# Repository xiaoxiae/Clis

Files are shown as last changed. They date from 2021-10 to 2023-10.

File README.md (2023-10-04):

_Project is **archived** and being reworked into something better. Soon launching at http://climbuddy.com/!_

---

<p align="center" width="100%">

</p>

<p align="center" width="100%">
The <strong>cli</strong>mber's <strong>s</strong>canner – efficient 3D scanning of climbing holds and climbing gym interiors.
</p>

## Introduction
This project contains everything you need to efficiently scan large set of holds (or other 3D objects, for that matter, if forked and adjusted accordingly) in a small amount of time. It uses an Arduino-powered turntable and camera to automatically take pictures, which it then converts to 3D models using the [Agisoft Metashape](https://www.agisoft.com/) photogrammetry software.

Additionally, it contains a tutorial for scanning climbing gym interiors, both of which can then be used in [Cled – the climber's editor](https://github.com/xiaoxiae/Cled).

For additional information, see the [thesis](https://github.com/xiaoxiae/Thesis).

## Setting up
For the setup, you'll need to first install `pyenv`:

```
# make sure to read what the script does before running it!
curl https://pyenv.run | bash
```

and configure your shell's environment: https://github.com/pyenv/pyenv#basic-github-checkout

You'll then need to install Python `3.7.x` (due to Metashape and Blender working only with older Python versions):

```
pyenv install -v 3.7.12
```

To set up the virtual environment, do (in this directory):

```
pyenv virtualenv 3.7.12 clis
pyenv local clis
pyenv activate clis
pyenv exec pip install -r requirements.txt
pyenv exec bpy_post_install # finds Blender and copies over some of its scripts
```

## Contents
Before running the scripts (using `pyenv exec`), it is advisable to check `config.py`, since a lot of the values will most likely differ from their default values for your particular setup.
Each of the respective folders contain a `README.md` that further explains the usage of each of the scripts.

### `01-scanning/`
Contains tools for scanning the holds.

### `02-processing/`
Contains tools for processing the hold images into 3D models.

### `03-data/`
Contains the hold data format specification and tools for managing the 3D models.

## Usage

### Using tasks
To simplify the usage of Clis, various pre-programmed scripts have been added:

- `tasks/add_models.sh` - model the newly added scans.
- `tasks/convert_from_raw.sh` - convert the raw copied files from RAW
- `tasks/copy_from_camera.sh` - copy the scanned sets from the camera
- `tasks/copy_from_path.sh <path>` - copy the scanned sets from the given path
- `tasks/generate_models.sh` - add the newly created models to the `holds.yaml` file.
- `tasks/mask_from_file_list.sh <file>` - mask the folders in the lines of the given text file
- `tasks/move_from_camera.sh` - move the scanned sets from the camera
- `tasks/scan_multiple.sh` - start scanning indefinitely
- `tasks/scan_single.sh` - scan a single time

To create a single model using them, you could do the following:
1. `./scan_single.sh` to scan a single hold,
2. `./move_from_camera.sh` to move the hold photos from the camera,
3. `./convert_from_raw.sh` to convert the photos to a usable format,
4. `./generate_models.sh` to generate the model and finally
5. `./add_models.sh` to add the model to the `holds.yaml` file.

### Using scripts
Run

```
pyenv exec python 01-scanning/01-scan.py automatic 15 && pyenv exec python 01-scanning/02-copy.py camera && pyenv exec python 01-scanning/03-convert.py
```

to automatically take 15 pictures of the hold, copy them from the camera and convert them from raw.
If you want to take them manually because you don't have the turntable, replace `automatic` with `manual`. Then run

```
pyenv exec python 02-processing/01-model.py
```

to generate the model.
Finally, run

```
pyenv exec python 03-data/01-add_models.py
```

to add the information about the hold to the `holds.yaml` dictionary.

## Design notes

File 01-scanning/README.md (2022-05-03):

# Scanning

## Scripts
The following describes the order in which the scripts should be called and what they do.

### `01-scan.py`
Scans the hold either automatically using the turntable (in which case it expects to be connected to it), or manually.
It must be connected to a camera that is supported by [gphoto2](http://gphoto.org/) (see [supported cameras](http://gphoto.org/proj/libgphoto2/support.php)).

### `02-copy.py`
Copies over the images from a local (user-readable) path, or the camera itself (connected via USB).

### `03-convert.py`
Converts the RAW hold photos to an image format (likely JPG) used for creating the models.
Uses [Darktable](https://www.darktable.org/)-CLI to do so.

### `04-mask.py`
Masks the images using the green color of the turntable.
Expects the list of files to do this to as a parameter.
Uses [OpenCV](https://pypi.org/project/opencv-python/) and [pyexiv2](https://github.com/LeoHsiao1/pyexiv2) (for metadata perservation).

## Turntable

### `markers/`
A folder containing a PDF with all 12-bit markers used for the scanning, along with their 3D models.

### `turntable/`
A folder containing the source code/documentation for the custom turntable used for turning the holds.

## `tutorials/`
Contais notes about scanning both the holds and the wall.

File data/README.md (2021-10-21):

# Data
The specification of the data format used for the climbing holds and the climbing wall.

## `holds.yaml`
A dictionary containing data of all holds.

```yaml
- Name: <hold name - sha256sum of the file>
  Color: <blue, yellow,...]>
  Type: <crimp, jug, sloper, pinch, pocket, foothold>
  Manufacturer: <the name of the manufacturer>
  Labels: [<a list of custom labels>]
```

## `holds/`
A folder containing the models of the holds in the `obj` format. Each should be:

- properly sized to correspond to the real world
- having correct origin (either in the middle or in some screw hole)
- facing upwards

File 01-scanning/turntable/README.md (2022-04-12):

# Turntable
A custom turntable powered by Arduino Uno.

Some numbers of the components vary (namely the motors), depending on how powerful you want the turntable to be, with the minimum being 1 and maximum being 3.

## Components
- 1x Arduino Uno (or some other Arduino with enough pins)
- 1x-3x A4988-based motor drivers
- 1x-3x bipolar stepper motors with a NEMA 17 interface
	- note: the length of mine is ~64mm (including the shaft), which is likely not standard; if you wish to use a different-sized NEMA 17 motor, edit the model accordingly (either the stl directly, or `parts/Turntable.f3d` in Fusion 360)
- 4x-12x M3 screws (motor mounts to motors), thread length 0.5cm
- 2x-6x M3 screws (motor mounts to body), thread length 1cm
- 2x-6x M3 nuts (motor mounts to body)
- 1x power supply for the motor(s)
- 1x superglue (if things don't fit properly)
- 7x 608 bearings

## Construction
1. print parts of the printer (found in the `parts/` folder):
	- 1x body
	- 1x top
	- 1x-3x motor mount
	- 1x-3x motor gear
2. add the bearings
3. put the mounts and gears on the motors (possibly using superglue)
4. wire and power everything
	- I used a small breadboard to make this step as easy as possible
	- Arduino expects the following mapping of pins to the A4988 sensor(s):
		- `2` -> `DIR`
		- `3` -> `STEP`
		- `4` -> `ENABLE`

<p align="center">
  Turntable Wiring Diagram
</p>

5. **tune the controllers:** https://ardufocus.com/howto/a4988-motor-current-tuning/
6. load the code to the Arduino (found in the `code/` folder)

After this, the Arduino can be controlled as seen in the `code/code.ino` script: it listens on the serial channel for the next string that it then converts to an integer and uses it as the turning angle. After the turning is done, it responds back with the same number it received (again as a string) and again starts to listen.

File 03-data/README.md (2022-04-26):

# Data

## Specification
The specification of the data format used for the climbing holds and the climbing wall:

```yaml
<sha256sum of the file contents (the first 12 characters)>:
  color: [<name of the color>, <hex value of the color>]
  type: <the type of hold (like crimp, jug, sloper, pinch, pocket, foothold, structure, etc.)>
  date: <the date the hold model was created>
  manufacturer: <the name of the manufacturer>
  labels: [<list>, <of>, <custom>, <labels>]
  volume: <a float volume of the hold>
```

## `01-add_models.py`
A script for adding the generated holds into the `holds.yaml` dictionary, automatically inferring their color from the texture in the process.

## `02-get-volume.py`
Calculate the volume of the given `obj` file, printing it to standard output.

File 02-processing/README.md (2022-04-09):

# Processing

## `01-model.py`
A script that converts sets of photos to models using [Agisoft Metashape Pro](https://www.agisoft.com/).
Only converts sets that don't yet have corresponding model folder.

## `02-clean.py`
A script that takes the model produced by Metashape and outputs the same model with the ground removed and simplified to a reasonable size.
It is _not meant to be called alone_ and is instead used in `01-model.py`.

## `03-retexture.py`
A script that takes the model and retextures it by reimporting it back to Metashape.

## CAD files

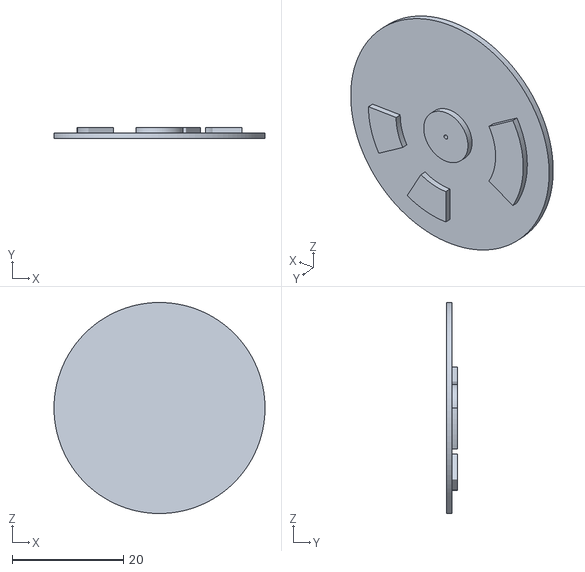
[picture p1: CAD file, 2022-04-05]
01-scanning/markers/models/9.stl
38.0 x 2.00 x 38.0

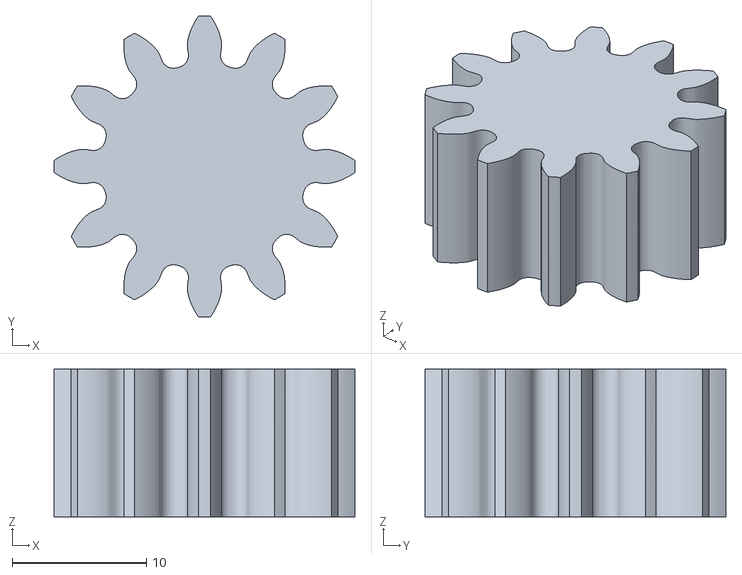
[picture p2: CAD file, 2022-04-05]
01-scanning/turntable/parts/Motor Gear.stl
22.4 x 22.4 x 11.0

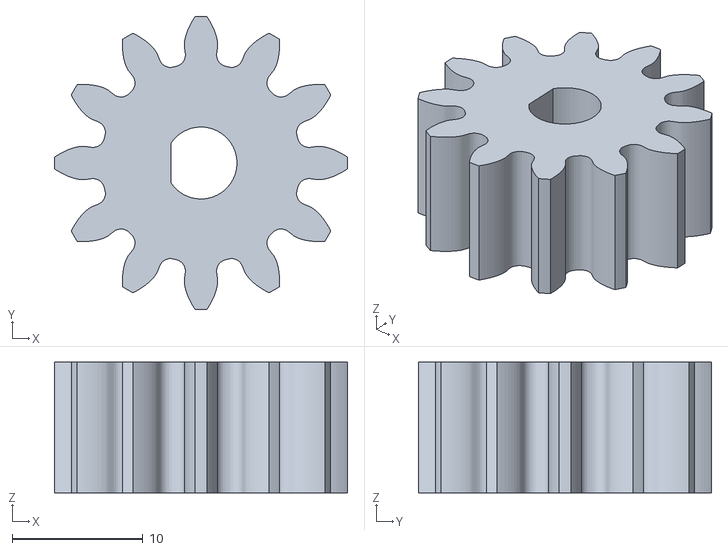
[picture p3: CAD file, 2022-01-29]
01-scanning/turntable/parts/Gear.stl
22.4 x 22.4 x 10.0

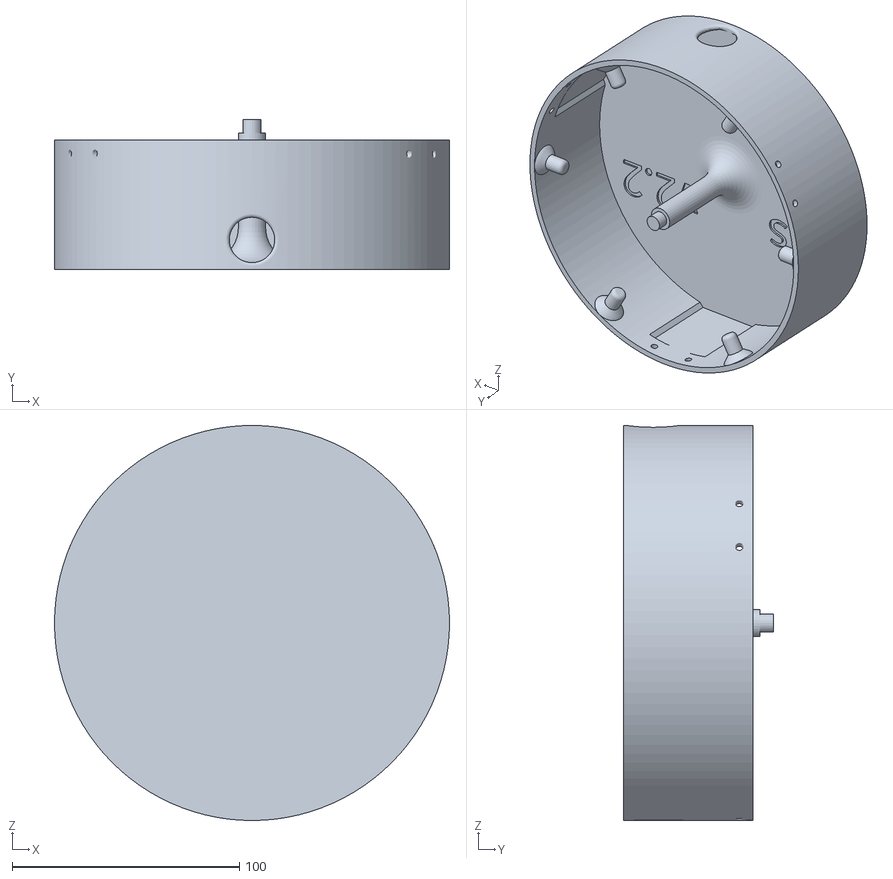
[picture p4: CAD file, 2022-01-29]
01-scanning/turntable/parts/Body.stl
174.0 x 66.0 x 174.0

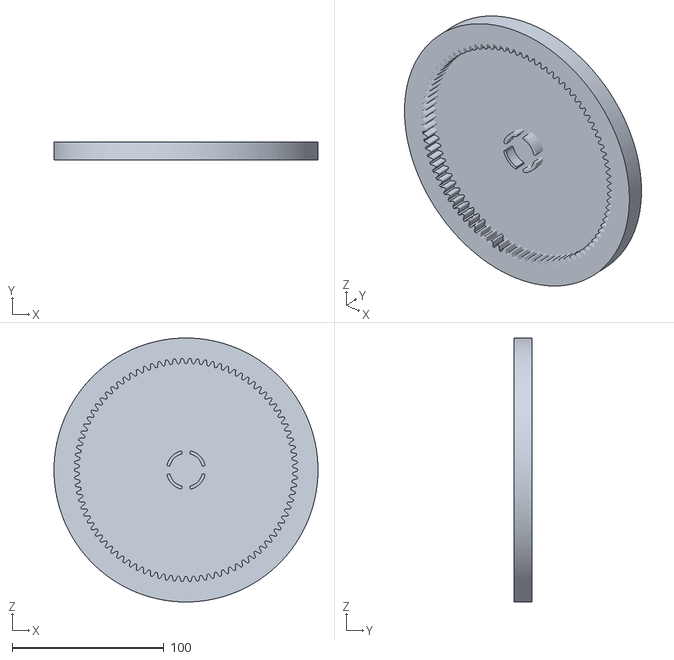
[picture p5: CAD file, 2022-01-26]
01-scanning/turntable/parts/Top.stl
174.0 x 12.0 x 174.0

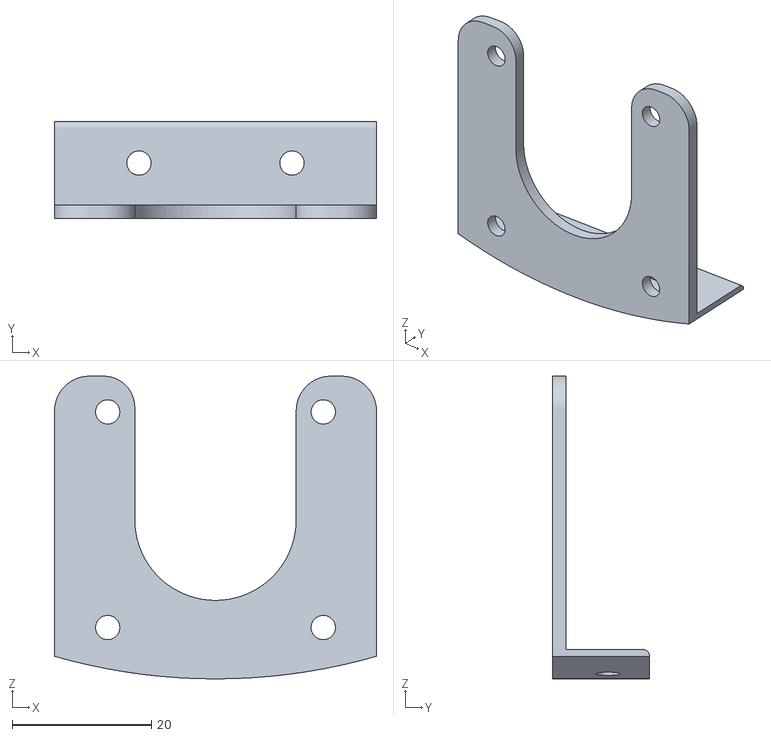
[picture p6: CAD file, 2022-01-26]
01-scanning/turntable/parts/Motor Mount.stl
46.3 x 14.0 x 43.5

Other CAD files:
01-scanning/markers/models/3.stl
01-scanning/markers/models/11.stl
01-scanning/markers/models/4.stl
01-scanning/markers/models/5.stl
01-scanning/markers/models/6.stl
01-scanning/markers/models/12.stl
01-scanning/markers/models/2.stl
01-scanning/markers/models/1.stl
01-scanning/markers/models/10.stl
01-scanning/markers/models/7.stl
01-scanning/markers/models/8.stl

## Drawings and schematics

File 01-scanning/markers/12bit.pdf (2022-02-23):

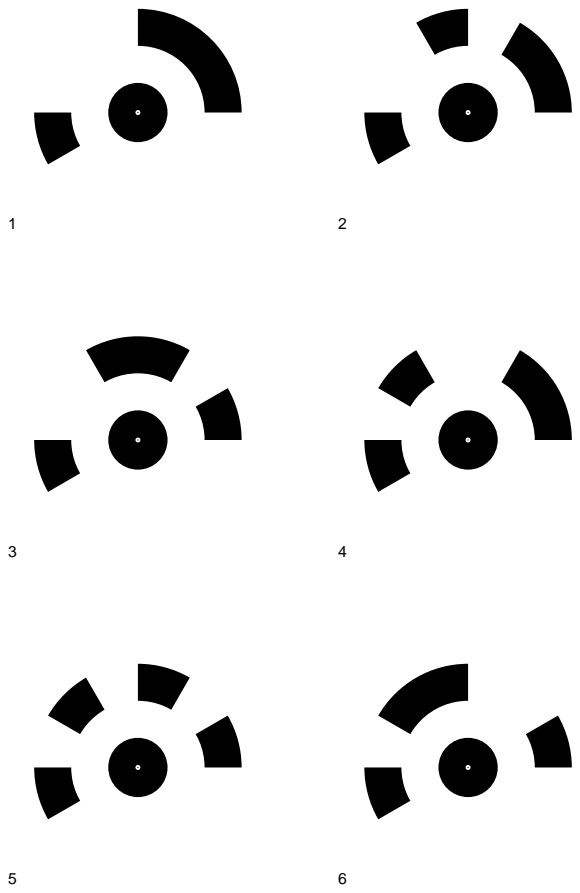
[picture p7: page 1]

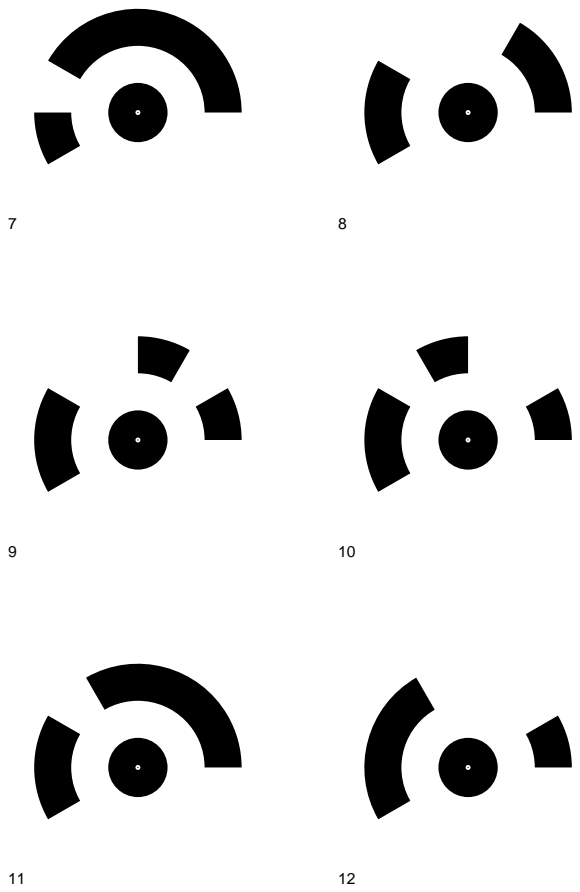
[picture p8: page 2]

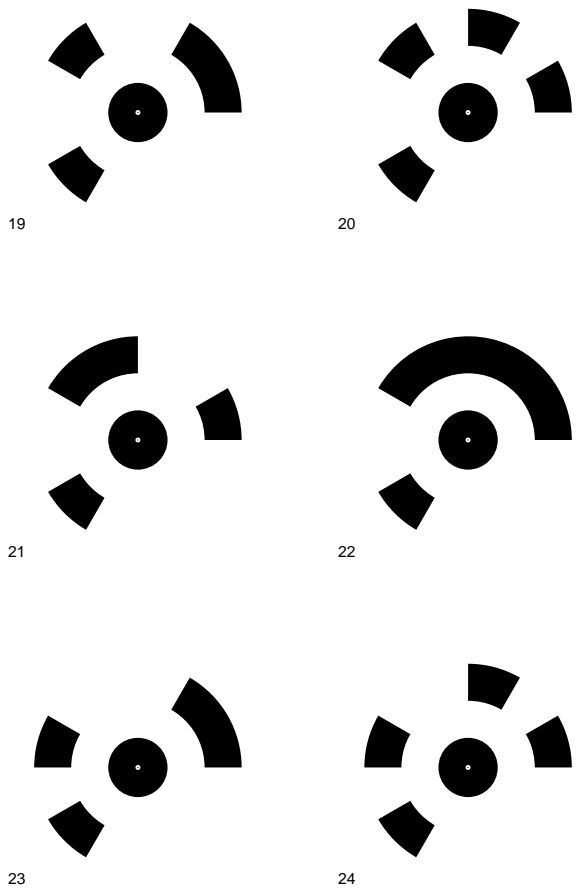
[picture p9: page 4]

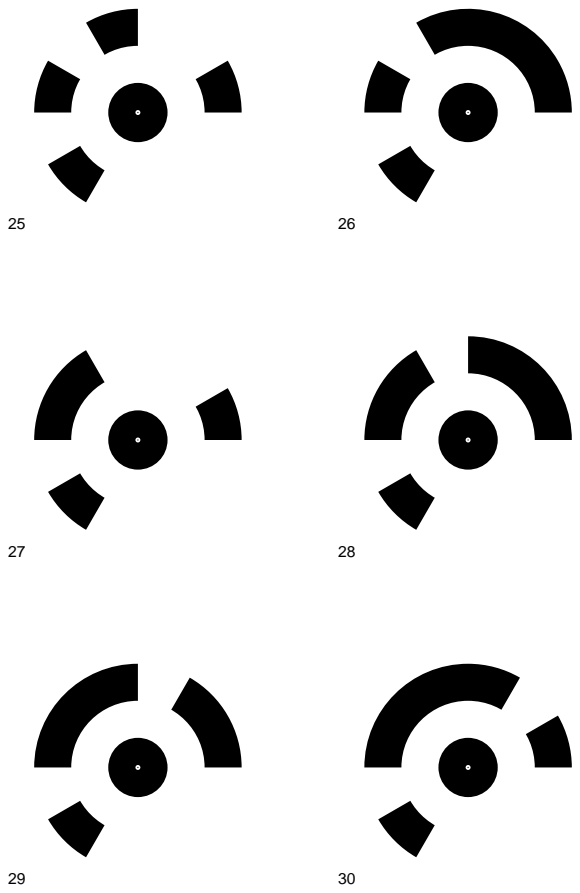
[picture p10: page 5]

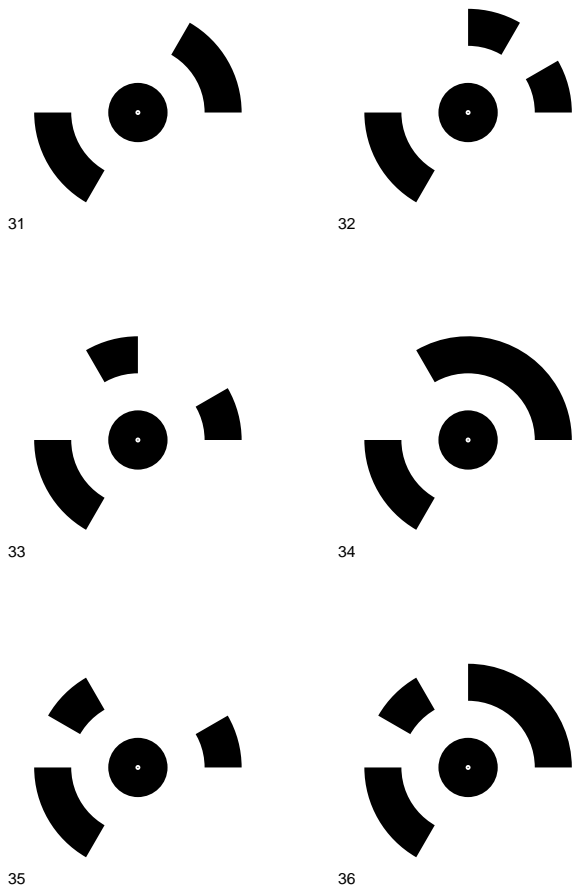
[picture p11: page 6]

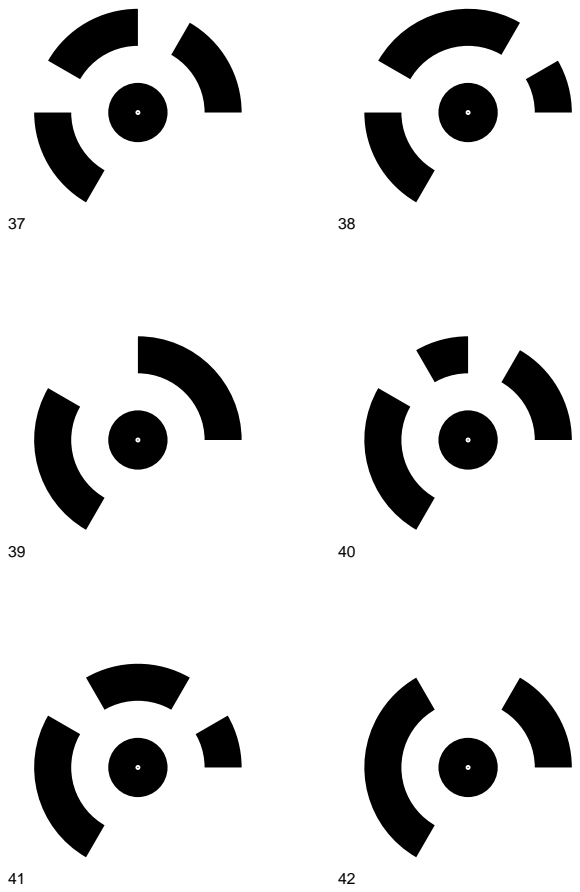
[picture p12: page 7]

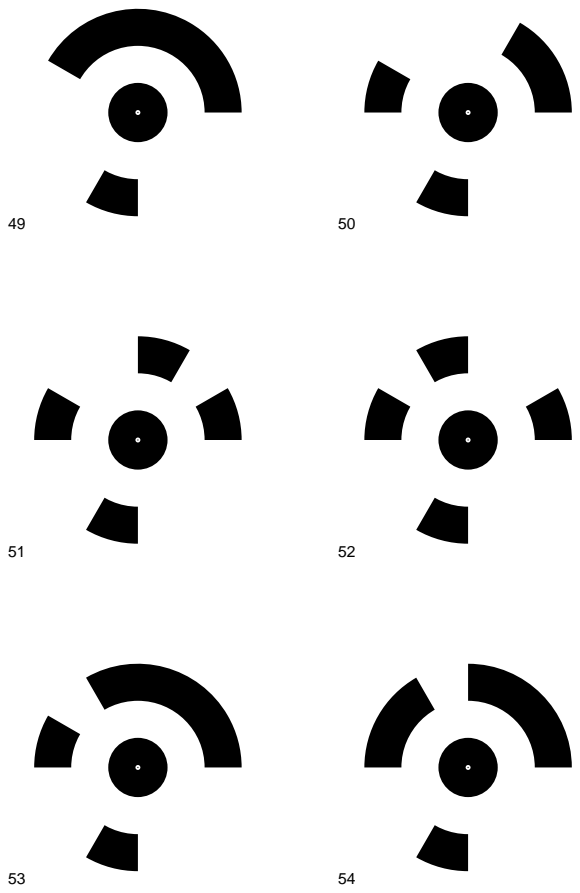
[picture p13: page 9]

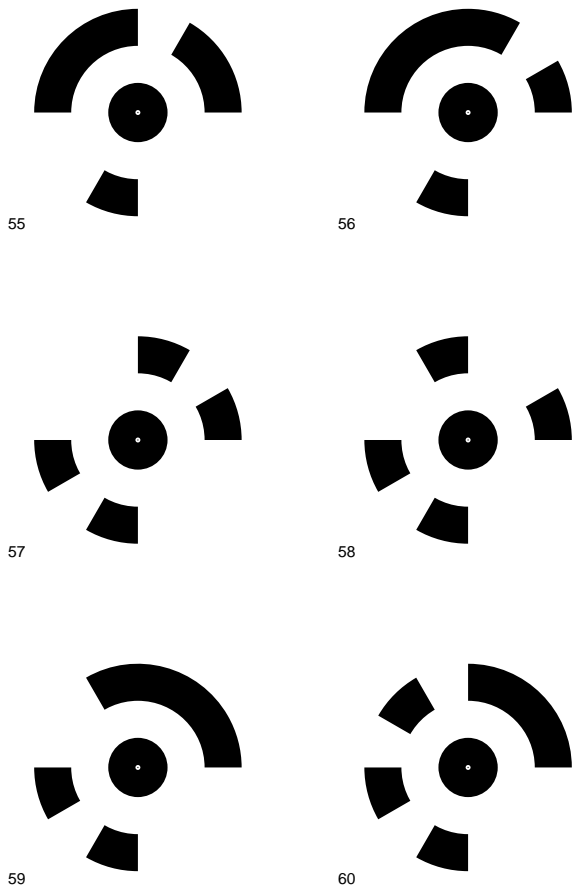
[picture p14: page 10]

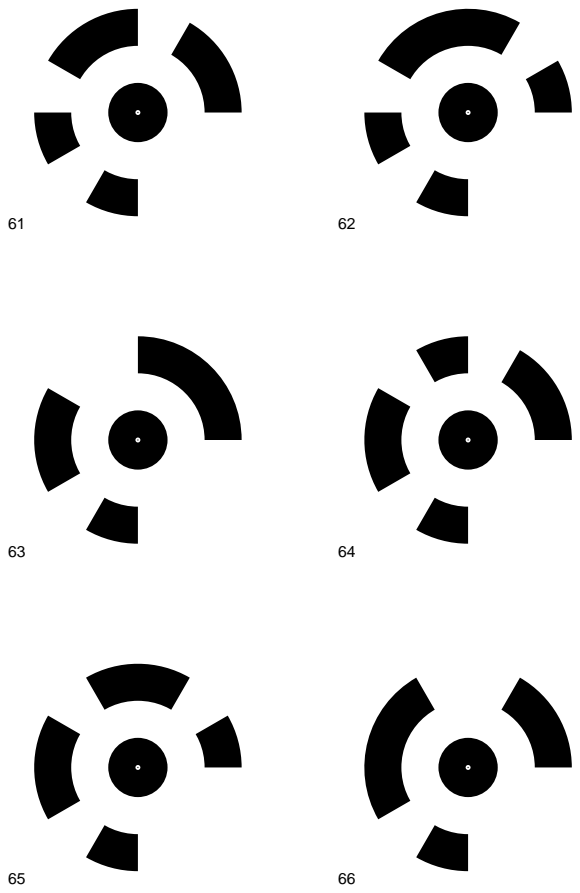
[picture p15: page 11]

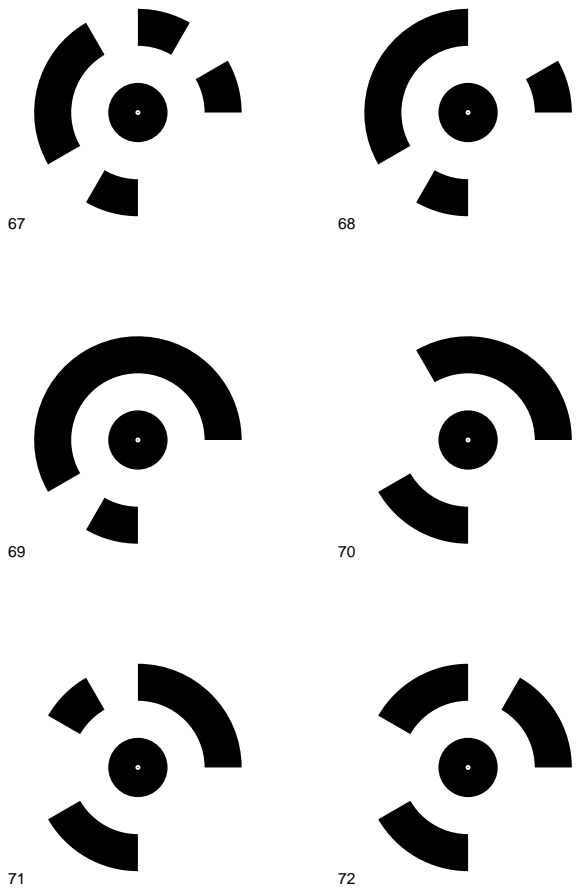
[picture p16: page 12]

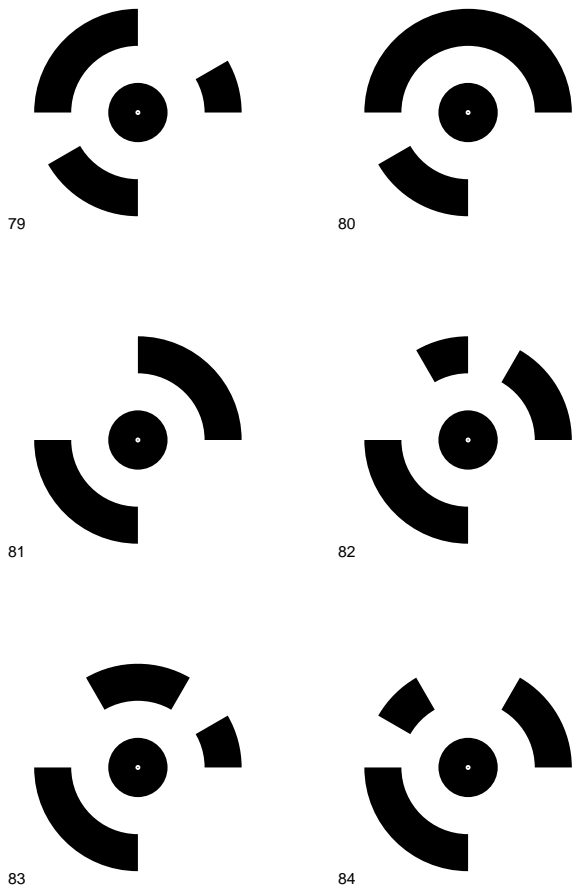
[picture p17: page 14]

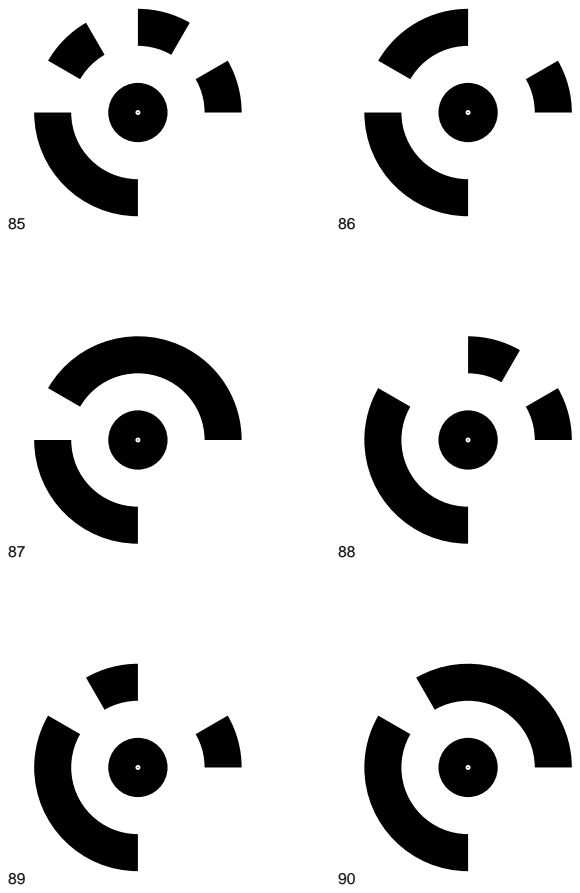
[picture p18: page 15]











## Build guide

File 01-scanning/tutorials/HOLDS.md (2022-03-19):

# Scanning climbing holds
A short tutorial on how to do photogrammetry on various types of climbing holds. Most of this is my personal opinion, formed by experimentation and various blog posts / YouTube videos about photogrammetry, so take it with a grain of salt.

I will leave links to the resources that I used while figuring things out where appropriate.

## Software used
The software used is [Agisoft Metashape Pro](https://www.agisoft.com/) using its Python bindings (see `../02-processing/README.md`). The program is relatively intuitive and simple to use, so I won't go into any detail regarding its GUI (there are many good tutorials out there that you can use if you're interested). You also likely won't need the GUI at all, since the scripts take care of everything.

## Setup
This approach covers **turntable-based photogrammetry**, meaning that the holds are on a turntable that is being captured by a stationary camera. This is essentially the same thing as turning the camera around the object (although arguably less convenient), since the background is uniform and the software has no way of telling the difference.

### Camera
I'm using the [Nikon Z 50](https://en.wikipedia.org/wiki/Nikon_Z_50) mirrorless camera to take the pictures and would suggest you use a camera too – while mobile phones produce fine photos, nothing can beat a good camera. Besides the quality of the images, it is also **extremely important** for the cameras to **contain metadata** about how the photo was taken (focal length, shutter speed, ISO, f/s), which is very useful to the photogrammetry process.

You should generally strive for low ISO (duh) and higher f/s, because you want the depth of field to be as large as possible – this makes it easier for the software to recognize key features to match between the photos, you really don't want the blur. Luckily, since (most) of the holds don't move, slower shutter speeds are quite acceptable to achive both low ISO and high f/s.

### Background
I'm using black background with a green turntable. The colors themselves aren't too important, but should be decently contrasting to the object being scanned – green holds on a green background could give the software some trouble.

### Markers
Besides the background, I use 3 markers to automatically adjust the object into its proper scale and location. This can be done quite trivially in the `Markers/` Metashape menu, where you can both generate a set of markers of desired size and also detect them in the images.

### Lighting
It is absolutely vital for the holds to be decently lit by **soft light**, ideally from multiple directions. This can be achieved by some less powerful LED lights (at most 20W) and appropriate mounting equipment. When bought right, this can be relatively cheap, but improve the quality of the scans by a large margin.

If the lights still produce light that is too hard, I'd suggest you put baking paper (or any other not-easily-flammable material) around them to better diffuse the light. This is miles cheaper than any diffuse filter you find on the market but yields similar results.

## On scanning various holds

### Dual-texture holds
When scanning dual-texture holds (and glassy holds in general), the software will have trouble finding enough features to produce a good model in the glossy area. To prevent this, I'd suggest you apply small amounts of chalk on the glossy parts.

### Large volumes
There is a pretty decent chance that you'll have to scan them outside the turnable, since they will be too large. I'd recommend placing them somwehere flat and again using markers to include in the images, since this means that you'll only have to do the "taking photos" part manually (using `01-scan.py manual`).

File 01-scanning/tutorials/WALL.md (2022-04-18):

# Scanning climbing walls
A short tutorial on how to do photogrammetry on various types of climbing walls. Most of this is my personal opinion, formed by experimentation and various blog posts / YouTube videos about photogrammetry, so take it with a grain of salt.

I will leave links to the resources that I used while figuring things out where appropriate.

## Overview
The basic idea is the following:
1. take photos of the wall
2. create a model some photogrammetry software (like [Metashape](https://www.agisoft.com/))
3. clean up the model using some 3D modelling software (like Blender)

Using this method, I managed to create a very detailed 3D model of the [Smíchoff climbing wall](https://www.lezeckecentrum.cz/cs/) in about 10 hours of work.

## Taking photos
Taking photos is the most crucial part of the entire process, since their quality will largely determine how accurate the model will be.

Use any device you can, but obviously the higher quality the better (I used my Nikon z50). When doing so, there are a few things to keep in mind:
- use different overlapping angles of each area you're capturing so the photogrammetry software has an easier time figuring everything out
- **do not change the area** that you're capturing by having people around or moving things about, else the reconstruction will most likely fail (or will exclude a lot of images, making the model inaccurate)
- the settings (ISO, shutter speed) and even the devices can differ between individual shots, but the photos should be as clear as possible and *should include the metadata** (namely the focal length), since the photogrammetry software uses this information to calculate the features

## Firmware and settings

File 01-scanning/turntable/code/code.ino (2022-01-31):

#include <AccelStepper.h>

#define dirPin1 2
#define stepPin1 3
#define enablePin1 4
#define dirPin2 5
#define stepPin2 6
#define enablePin2 7
#define dirPin3 8
#define stepPin3 9
#define enablePin3 10

#define motorInterfaceType 1

#define stepsPerRevolution 200
#define gearRatio 90.0f / 12.0f
#define angleCoefficient (int)(stepsPerRevolution * gearRatio)


#define max_speed 300.0
#define max_acceleration 400.0
#define speed_coefficient 0.8

AccelStepper stepper1 = AccelStepper(motorInterfaceType, stepPin1, dirPin1);
AccelStepper stepper2 = AccelStepper(motorInterfaceType, stepPin2, dirPin2);
AccelStepper stepper3 = AccelStepper(motorInterfaceType, stepPin3, dirPin3);


void enable_motor() {
  digitalWrite(enablePin1, LOW);
  digitalWrite(enablePin2, LOW);
  digitalWrite(enablePin3, LOW);
}

void disable_motor() {
  digitalWrite(enablePin1, HIGH);
  digitalWrite(enablePin2, HIGH);
  digitalWrite(enablePin3, HIGH);
}


void setup() {
  stepper1.setMaxSpeed(max_speed);
  stepper1.setAcceleration(max_acceleration);
  stepper1.setSpeed(max_speed * speed_coefficient);
  
  stepper2.setMaxSpeed(max_speed);
  stepper2.setAcceleration(max_acceleration);
  stepper2.setSpeed(max_speed * speed_coefficient);
  
  stepper3.setMaxSpeed(max_speed);
  stepper3.setAcceleration(max_acceleration);
  stepper3.setSpeed(max_speed * speed_coefficient);

  pinMode(enablePin1, OUTPUT);
  pinMode(enablePin2, OUTPUT);
  pinMode(enablePin3, OUTPUT);

  disable_motor();

  Serial.begin(9600);
}

int angleToRevolutions(int angle) {
  return (int)((angle / 360.0) * angleCoefficient);
}

void loop() {
  if (Serial.available() > 0) {
    long angle = Serial.readString().toInt();

    enable_motor();
    stepper1.setCurrentPosition(0);
    stepper1.moveTo(angleToRevolutions(angle));
    
    stepper2.setCurrentPosition(0);
    stepper2.moveTo(angleToRevolutions(angle));
    
    stepper3.setCurrentPosition(0);
    stepper3.moveTo(angleToRevolutions(angle));

    while (stepper1.distanceToGo() > 0 && stepper2.distanceToGo() > 0 && stepper3.distanceToGo() > 0) {
      stepper1.run();
      stepper2.run();
      stepper3.run();
    }
    
    disable_motor();

    Serial.println(angle, DEC);
  }
}

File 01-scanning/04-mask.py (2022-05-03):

import cv2
import numpy as np
import shutil
import sys
import os
import argparse
import pyexiv2
import tempfile
from subprocess import Popen, PIPE
from glob import glob

sys.path.append("..")

os.chdir(os.path.dirname(os.path.abspath(__file__)))

from config import *
from utilities import *


def get_convex_hull_mask(image):
    """Get the mask using the convex hull of green pixels. Currently unused (but kept as a pet)."""
    hsv = cv2.cvtColor(image, cv2.COLOR_BGR2HSV)

    lower_green = np.array([65,60,60])
    upper_green = np.array([80,255,255])

    mask = cv2.inRange(hsv, lower_green, upper_green)

    kernel = np.ones((5,5),'int')
    dilated = cv2.dilate(mask,kernel)

    res = cv2.bitwise_and(image,image, mask=mask)

    ret, thresh = cv2.threshold(cv2.cvtColor(res,cv2.COLOR_BGR2GRAY),3,255,cv2.THRESH_BINARY)
    contours, hierarchy = cv2.findContours(thresh, cv2.RETR_LIST, cv2.CHAIN_APPROX_SIMPLE)

    # create hull array for convex hull points
    hull = []
    for contour in contours:
        hull += list(contour)

    hull = cv2.convexHull(np.array(hull), False)
    hull = np.array([[h[0] for h in hull]])

    # create an empty black image
    drawing = np.zeros(image.shape[:2], np.uint8)

    cv2.fillPoly(drawing, hull, (255, 255, 255))

    return drawing


def get_contour_mask(image):
    """Get the image by using contours from the pixel threshold."""
    gray = cv2.cvtColor(image, cv2.COLOR_BGR2GRAY)

    ret, thresh = cv2.threshold(gray, MASKING_THRESHOLD, 255, cv2.THRESH_BINARY)

    # detect the contours on the binary image using cv2.CHAIN_APPROX_NONE
    contours, hierarchy = cv2.findContours(image=thresh, mode=cv2.RETR_TREE, method=cv2.CHAIN_APPROX_NONE)

    # find the biggest countour (c) by the area
    c = max(contours, key = cv2.contourArea)

    # create an empty black image
    drawing = np.zeros(image.shape[:2], np.uint8)
    cv2.fillPoly(drawing, np.array(c), (255, 255, 255))

    # flood fill from origin on black pixels
    cv2.floodFill(drawing, None,
            seedPoint=(image.shape[1] // 2, image.shape[0] // 2),
            newVal=(255, 255, 255),
            loDiff=(1, 1, 1, 1), upDiff=(1, 1, 1, 1))

    # smoothen a bit
    kernel2 = np.ones((5, 5), np.float32)/25
    img = cv2.filter2D(src=drawing, ddepth=-1, kernel=kernel2)

    return drawing


printer = Printer("mask")

parser = argparse.ArgumentParser()
parser.add_argument("folders", nargs='+', help="The folders to process the images of")

arguments = parser.parse_args()

for folder in arguments.folders:
    printer.full(f"masking images from '{folder}':")
    for name in sorted(glob(os.path.join(folder, "_*.jpg"))):
        printer.begin(f"masking '{name}'")

        image = cv2.imread(name)

        mask = get_contour_mask(image)

        resulting = cv2.bitwise_and(image, image, mask=mask)

        tmpfilename = os.path.join(
            tempfile._get_default_tempdir(),
            next(tempfile._get_candidate_names()) + ".jpg"
        )

        cv2.imwrite(tmpfilename, resulting)

        Popen(["exiftool", "-TagsFromFile", name, "-all:all>all:all", tmpfilename],
                stdout=PIPE, stderr=PIPE).communicate()

        os.remove(name)
        shutil.move(tmpfilename, name)

        printer.end("done.")

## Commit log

2021-10-15 scanning: Arduino code
2021-10-16 turntable: code + basic README.md
    [Body.stl, Top.stl]
2021-10-17 turntable: object
    [Body.stl, Mid.stl, Top.stl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]
2021-10-21 scanning: catch keyboard interrupt
2021-10-22 scanning: Arduino code + protocol (finalized)
2022-01-24 turntable: code for 3 motor drivers
2022-01-26 turntable: proper angle coefficient for 3 motor turntable
2022-01-26 turntable: v2.1 models + up-to-date README
    [Body.stl, Mid.stl, Motor Mount.stl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]
2022-01-26 wall: boulder section model
    [model.blend, model.stl]
2022-01-29 scanning: -conversion (slows things down), +user interrupt handling
2022-01-29 scanning: up-to-date turntable model
    [Body.stl, Gear.stl]
2022-01-31 scanning: auto focus the camera between shots
2022-02-18 restructuring
    Made to make the workflows more intuitive.
    [Body.stl, Gear.stl, Motor Mount.stl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]
2022-02-21 scanning: copy: add camera mode
    Quite useful for development as you can chain 01, 02 and 03 together in a single call.
2022-02-26 scanning: remove background
    It turns out that it's completely useless. The current iteration of the method uses only markers, which are more than fine.
2022-03-01 processing: markers before camera alignment
    It should help, right?
2022-03-09 data: exclude wall (for now)
    [model.blend, model.stl]
2022-03-14 processing: warn when not all cameras are aligned
2022-03-22 scanning: print the total number of taken photos
2022-03-22 scanning: convert prints where it's at
2022-03-28 everything: sort when printing stuff out
2022-03-28 scanning: only print 'viewing folder' when something is converted
2022-03-28 scanning: pass printers to initialize_camera
2022-04-03 scanning: infinite holds interrupt
2022-04-03 scanning: longer sleep between reading camera files
2022-04-05 scanning: better READMEs + gear and marker models
    [1.stl, 10.stl, 11.stl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]
2022-04-10 scanning: inital import camera code
    It currently works horribly, because the parameters have to be changed correctly in the imported xml file (otherwise the model is garbage). Currently put on the backlog.
2022-04-12 scanning: turntable SVG diagram
    [Diagram.fzz]
2022-05-01 processing: print exception when generation fails
2022-05-03 scanning: correct mask flood-fill origin + verbose print
    [04-mask.py]
2022-05-03 processing: clean-up after keyboard interrupt
2022-05-06 Update wiring diagram
    [Diagram.fzz]
